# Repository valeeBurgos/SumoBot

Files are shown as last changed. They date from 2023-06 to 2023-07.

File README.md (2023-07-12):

# SumoBot
In this repository you will find all the information to build a sumo robot.

A sumo robot is a type of robot designed to compete in the sport of robotic sumo, a competition in which robots compete to push their opponent out of a circular ring using a variety of techniques and strategies. Sumo robots are generally small and round, with a large amount of power in their motors to forcefully push their opponent.

In robotic sumo competitions, robots must adhere to certain rules, such as the maximum size and weight allowed, and must be able to detect ring lines and avoid cheating. Sumo robots must also be able to operate autonomously during combat, as human controllers are not allowed in the ring.

### Hardware
In the "Hardware" folder you can find everything related to the physical development of the project, including the list of commercial materials, materials manufactured with indications and original files (for example, 3D printing), assembly instructions, observations and recommendations.
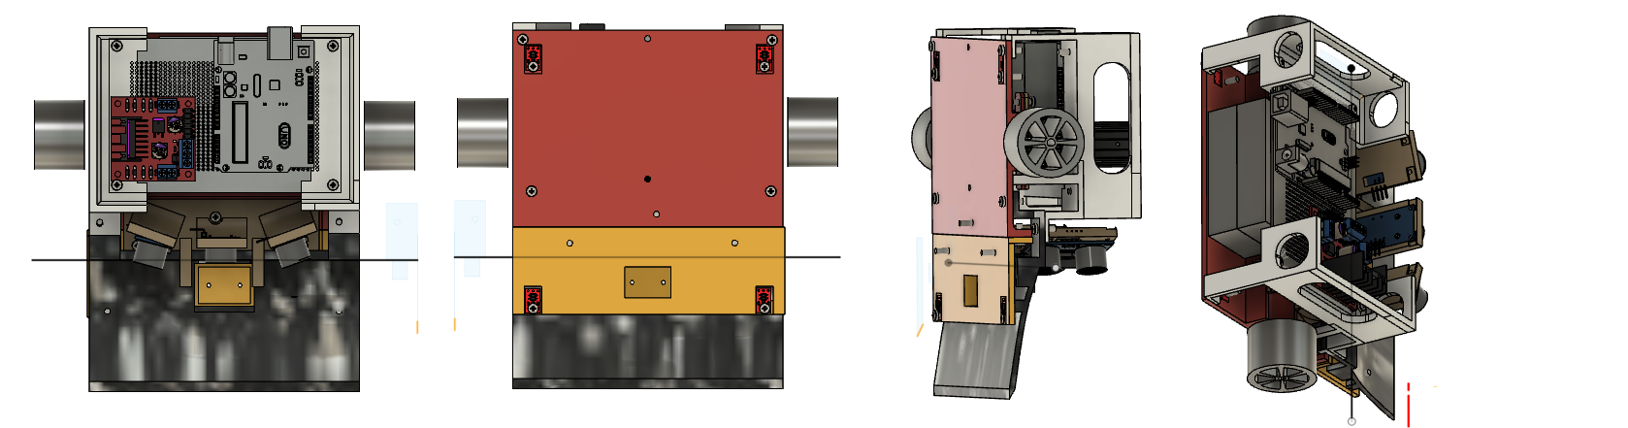
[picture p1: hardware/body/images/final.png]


### Software
In the "Software" folder you can find what is related to the code used. This is programmed in Arduino IDE and the algorithm will be explained in general terms.

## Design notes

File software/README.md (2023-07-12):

# SumoBot: body

Here is the code implemented for the robot.

### Technical details:
- UNO R3: Open-Source electronic board based on an ATMega microcontroller
- Programmed in Arduino IDE

### Pines
You can find all the information of the pins in the folder "circuit".

### Algorithm explanation

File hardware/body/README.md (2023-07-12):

# SumoBot: body

In this folder you will find everything you need to assemble the physical part of the robot discounting the circuit.
This includes (with images):
1. List of commercial components.
2. Links original files for 3D printing in GrabCAD.
3. Printing instructions
4. Assembly instructions.
6. Recommendations and observations

## Commercial components
- 1 x UNO R3 (UNO Full Microcontrolador Compatible, based on an ATmega microcontroller) (1)
- 2 x Motor Reductor 192rpm marca Troy modelo Luxor 25GA 12V (2)
- 1 x Driver L298N Puente H (3)
- 1 x Linear Regulator L7805CV  (4)
- 3 x Sensor Ultrasonico HC-SR04 (5)
- 3 x Push Button Momentary Switch 12mm (6)
- Floureon LiPo Battery 7,4 V 1500 mAh (7)
- 4 x analog Infrared reflective sensor 1-a (8)
- 1 x Universal protoboard (8 cm x 12 cm)  (9)
- mini 3PI car N20 Caster (10)
- Cabos  (11)
- 2 x conector T-DEAN (12)
- 24 x M3 x 10        (13)
- 24 x tuercas 3 mm   (14)
- 8 x M2 x 10         (15)
- 1 x resistor 47k    (16)

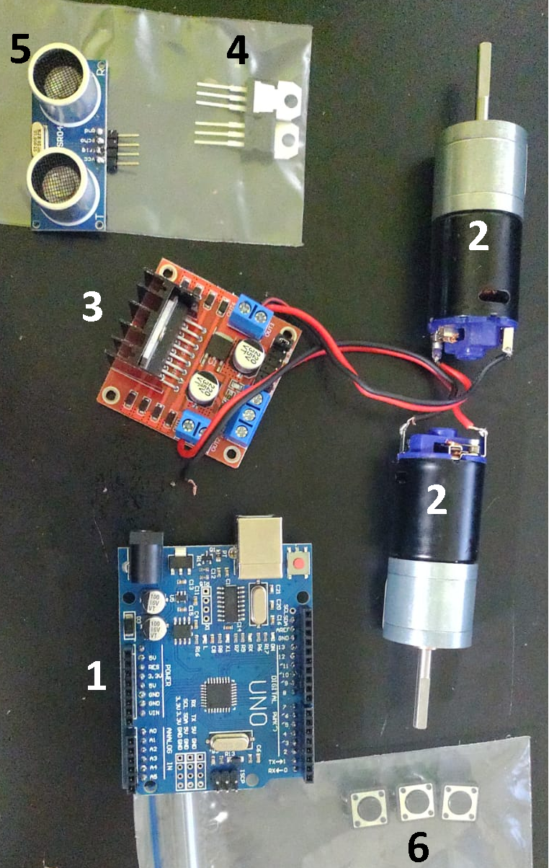
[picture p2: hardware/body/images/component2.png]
Component 2
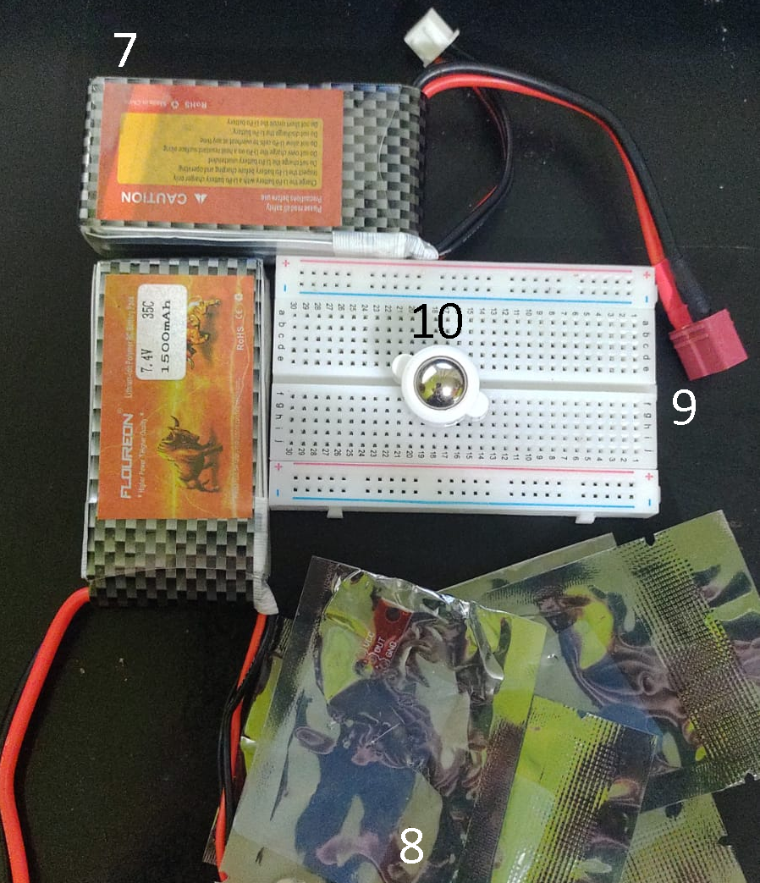
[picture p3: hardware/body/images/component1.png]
Component 1
|  |  |
| :---: | :---: |

## 3D components
To manufacture this robot, 3D printing was produced as the main manufacturing resource. Fusion360 was used to create the models, supporting commercial component models created by the community.

In [this link](https://grabcad.com/library/robot-sumo-10) you can find the necessary components, in .step and .f3d format (except those obtained from the community for commercial components that are only in .step format)

Inside the CAD folder you will find the following files:
- Base delantera (1)
- Base trasera (2)
- Soporte Ultrasonido (3)
- Rampa (4)
- Segundo piso 1 (5)
- Segundo piso 2 (6)
- Rueda (7) *
- Soporte motor (8) *

Whose number in parentheses corresponds to those labeled in the following image
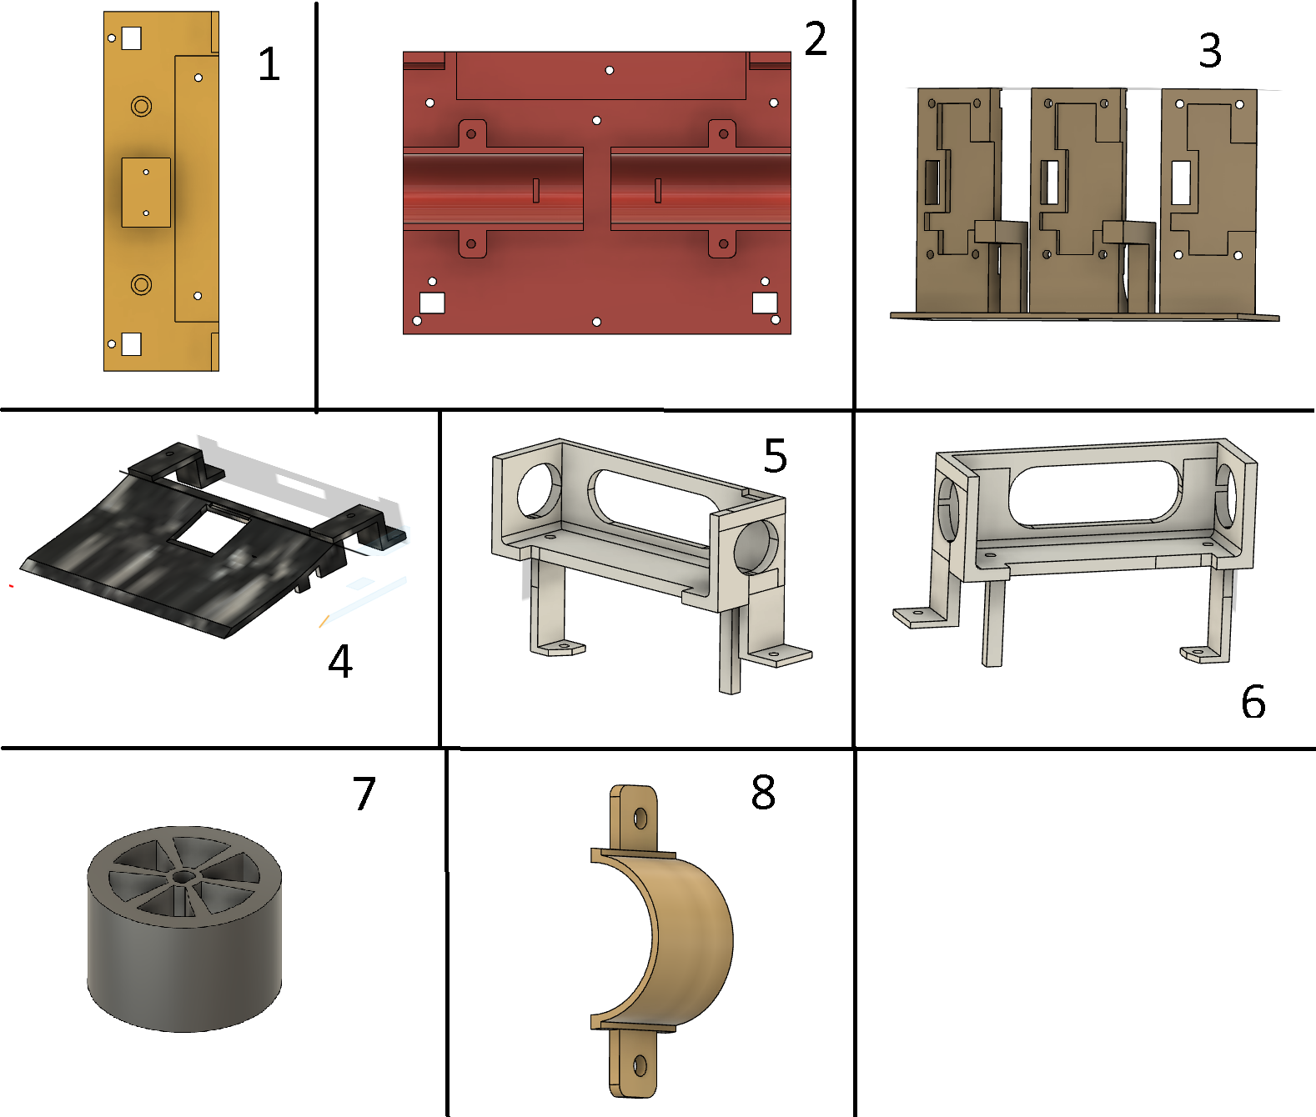
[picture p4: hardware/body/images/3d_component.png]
3D components


In the components folder you can find the commercial components used in .stl format. These are not to be printed, only used for a better visualization of the space.

## Printing instructions
To print these 8 components, it is considered that those marked with an * must be printed 2 times, since there are 2 wheels and motors that need support.

For this, an ender3 printer is used with the following parameters:
Wall : 2
Infill : 30%
Fill pattern :grid
Initial Layer Height : 0.28
Layer height : 0.32
Filament : PLA

The printing of all these pieces, in total, takes several hours. The files used are those that are in .stl format, so they do not need further adaptations.

## Assembly instructions
1. Base
As a first step, what can be seen in the image is assembled.
This corresponds to the following:
- 4 QTR-1d sensors to the base each with 1 bolt and nut M3 x 10
- Assemble the same to the ultrasonic sensor supports, using 4 M2 x10 bolts for each of the sensors.
- Motors on their respective supports held by part 8. 2 M3 x 10 nuts and bolts are used for each motor.
- The two parts of the base are joined with 2 M3 x 10 bolts with nuts.
- Piece 3 is joined with three M3 x 10 people. This piece also joins the two parts of the base.
The expected result is the one in the photo.
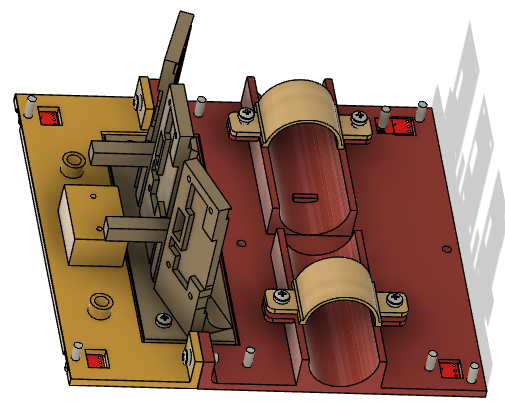
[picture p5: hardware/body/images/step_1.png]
1 step


2. First electrical connections

To each added sensor, use an arduino cable and connect it. Ideally, these connections should be soldered. For now, the other end is not connected.

3. Second layer of assembly
- In this step, pieces 5 and 6 are joined, which correspond to the second floor where the plate will be left. For this, 2 M3 x 10 bolts are used.
- Piece 4 is assembled. This is done by fitting the hole in the middle with the box of piece 1, in the lower part it has some cylinders that must be fitted with piece 1.
- Part 4 is joined to part 2 using 2 M3 x 10 bolts.
- Piece 4 is joined with pieces 5 and 6 with two M3 x10 buts.
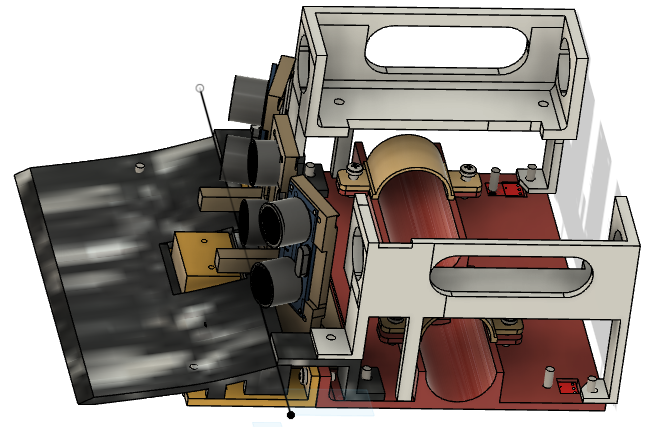
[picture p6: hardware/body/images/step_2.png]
3 step


4. Circuit in universal protoboard

The circuit is then prepared. For this, a universal breadboard is used.
- Solder microcontroller to breadboard. It is important to leave space on the arduino to upload the program, access must be easy.
- Solder L298N to the breadboard 
- A button is welding to the breadboard.
- Paths are made on the breadboard to join the elements as indicated in the instructions in the circuit folder.
- A small breadboard resting on part 2 is used to connect gnd and 5v to all the sensors.
- With arduino cables, the sensors are connected to the microcontroller.

Separately, connect the batteries in series. For this, piece 12 is used. If you have a single battery with sufficient voltage, this can be omitted. You must connect the ground with the rest of the circuit, connect the battery to the L298N and to the voltage regulator, from which the microcontroller and sensors are fed. 
In general, it is as follows:
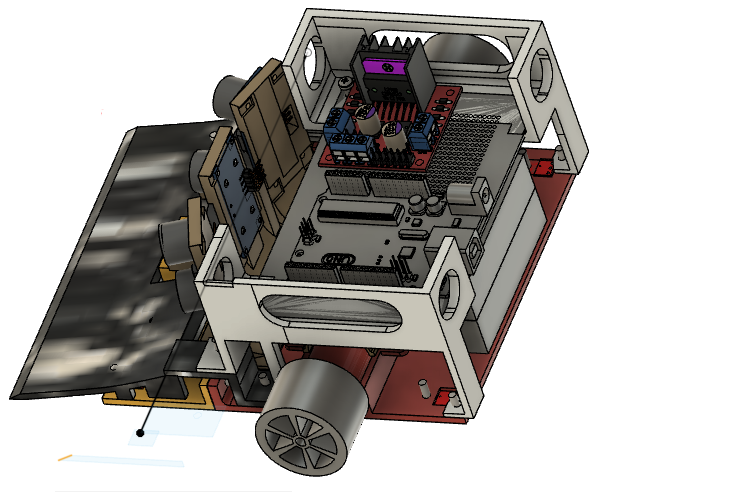
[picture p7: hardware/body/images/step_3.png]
4 step

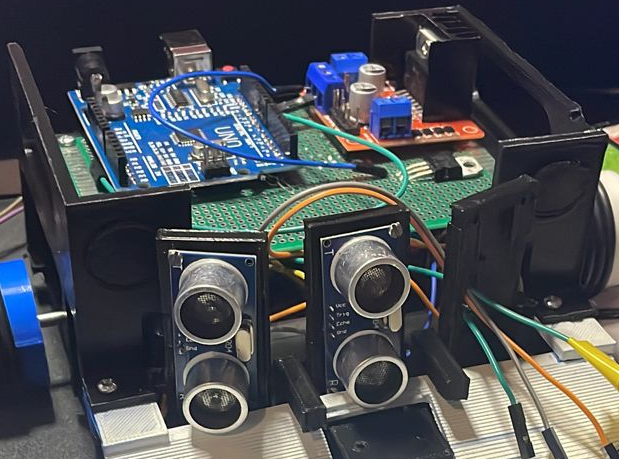
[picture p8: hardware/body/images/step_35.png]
4 step


5. Last step

Attach wheels to engines carefully.
Confirm that the battery is firm.
Secure the breadboard with 4 bolts to parts 5 and 6.  

## Recommendations and observations
- It is important to have separately reviewed the circuit. Care must be taken in the connections.
- Separately printed parts are weak, they must be handled with care. Once assembled the structure is much more resistant
- It is important to follow the order in which the elements are connected. Otherwise it may not be possible to locate bolts correctly due to small gaps.
- The box of part 1 is to locate some point of contact with the ground to manage stability. They serve many elements, but it is recommended to use the commercial component 10.
- The connections must be made at the indicated time or there is a risk of not having enough space, for example below the ramp there are 2 sensors that must be wired before positioning it.

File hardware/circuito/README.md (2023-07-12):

# SumoBot

In this folder you can find:
- A .pdf file named "sumo_circuit" with the connections of the circuit made in Kicad 6.0
- Explanation of the microcontroller pins used.
- Recommendations for the implementation of the circuit.

### components
Component specifications can be found in the list of commercial components [here](https://github.com/valeeBurgos/SumoBot/tree/main/hardware/body)

### Pins

The connections to the Arduino Uno R3 board are listed below. First, the digital pins are listed in order, followed by the analog pins.

Digital pins:
- 13 EchoM 
- 12 TrigL
- 11 EchoR
- 10 TrigR
- 9 ENA
- 8 IN1
- 7 IN2
- 6 EchoL
- 5 TrigM
- 4 IN4
- 3 ENB
- 2 IN3

Where the pins with the words Trig and Echo belong to ultrasound sensors. The letters that accompany it indicate its position: L is left, R right, M is middle.
The pins belonging to the system to control the motors are ENA, IN1, IN2, ENB, IN3, IN4.

Analog pins:
- A0 S1
- A1 S2
- A2 S3
- A3 S4
- A4 button

The connected pins correspond to the infrared sensors for line detection. In this case, they are digital pins but the analog inputs are used.
A button is also connected to an analog input.

### Notes
1. You can notice that almost all available pins of the place are used. If you want to add new elements, you must consider the space or change the microcontroller.
2. Infrared and ultrasonic sensors can interchange pins with respect to their same type. If these are interchanged, the code must be changed to ensure correct operation and expected behavior.
3. A 16V voltage is being used, but a 12V source is sufficient.
4. A regulator is used to go from 16V to 5V to power the microcontroller and sensors. It is important not to connect directly to 16V.
5. It is considered a good option to use a switch to control the power. It is not implemented in this circuit.

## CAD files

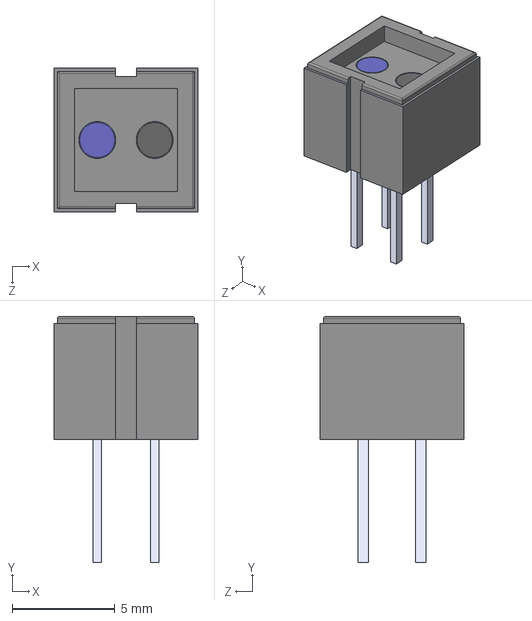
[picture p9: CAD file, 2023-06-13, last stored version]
hardware/circuito/librerias/CNY70/CNY70.step
7.00 x 12.0 x 7.00 mm

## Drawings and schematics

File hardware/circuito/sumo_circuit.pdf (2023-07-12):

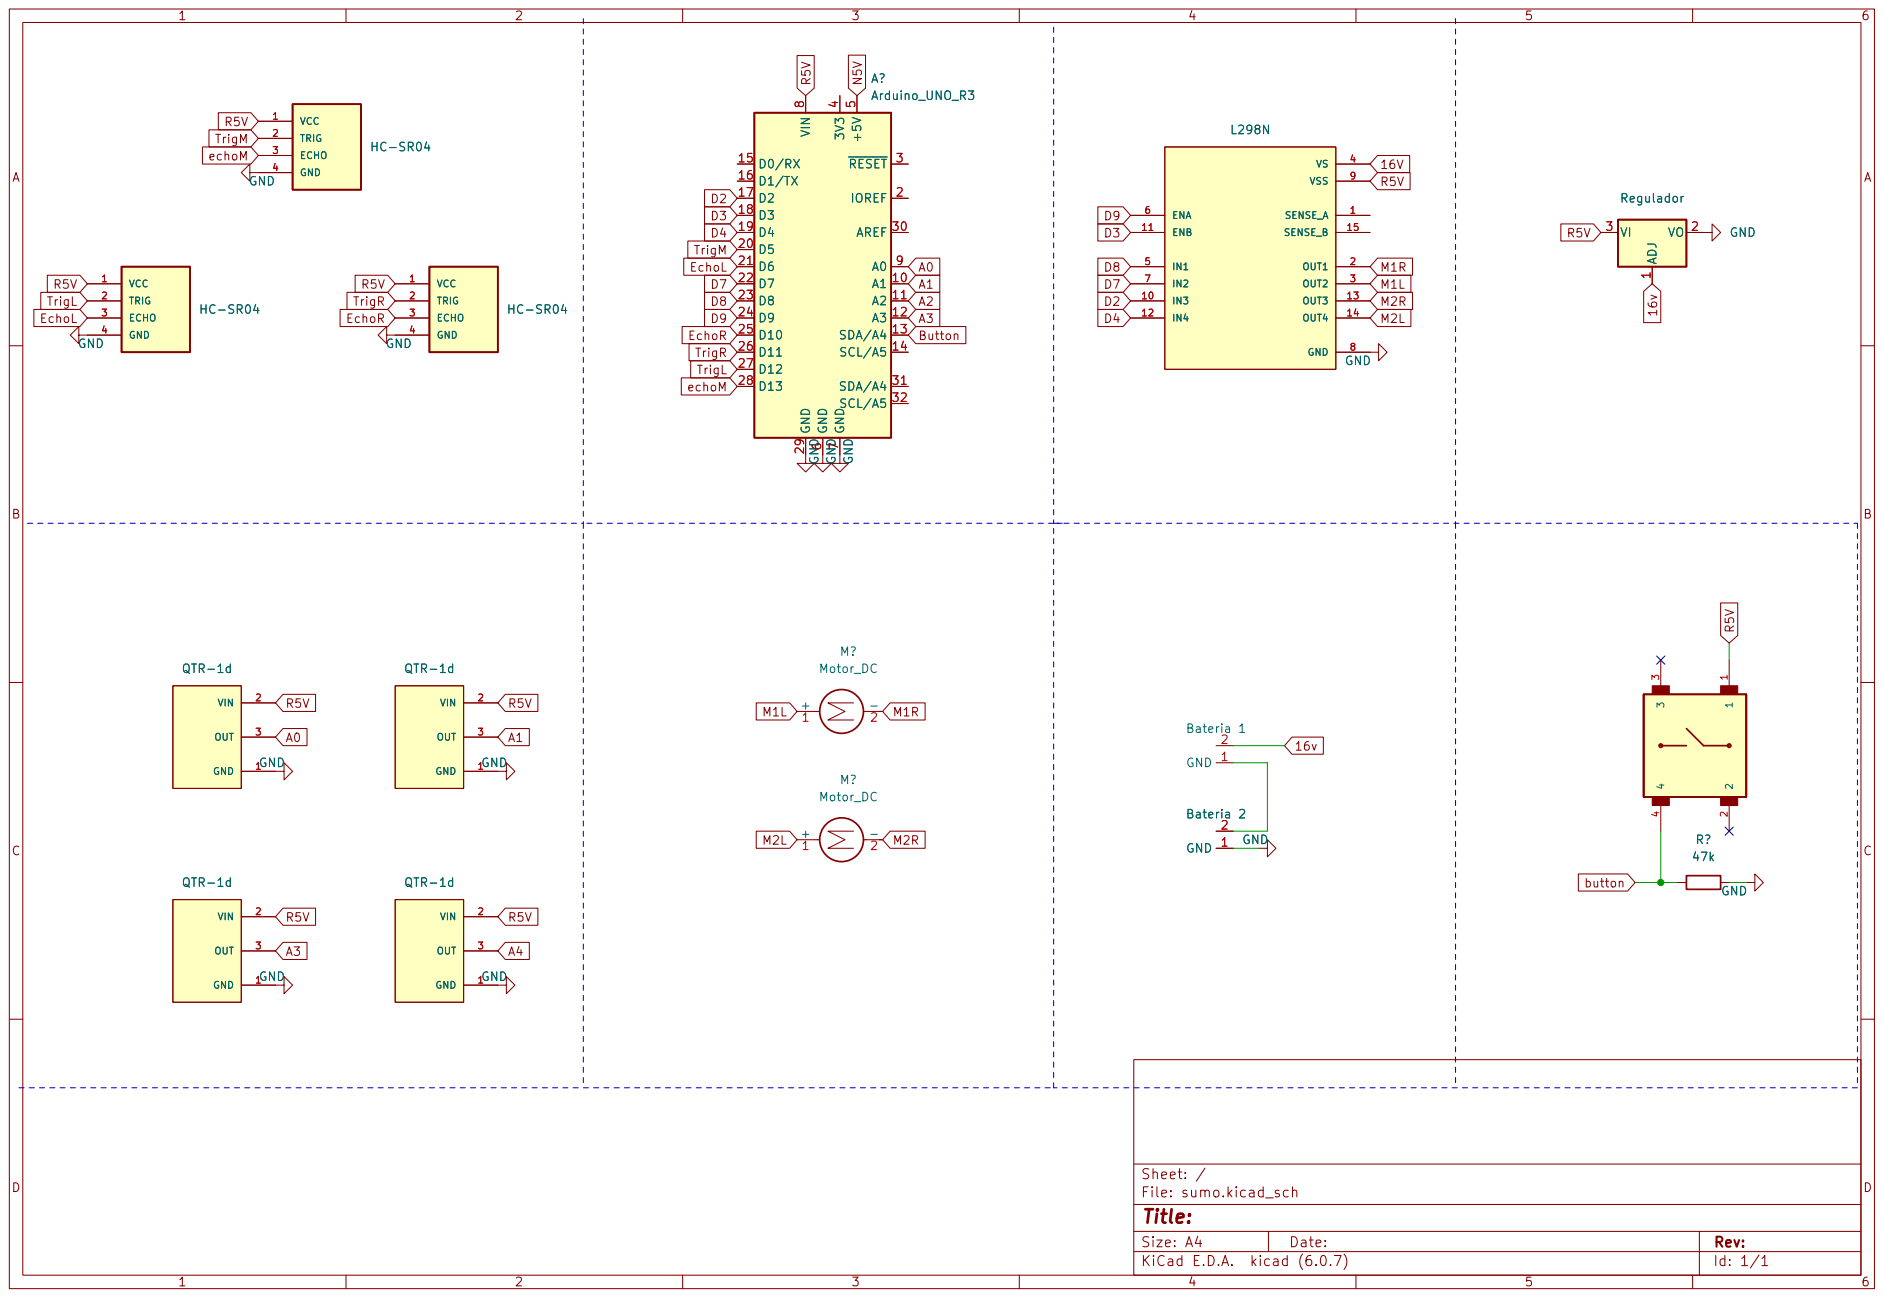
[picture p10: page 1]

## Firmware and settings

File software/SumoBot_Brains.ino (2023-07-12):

#include <Button.h>
//Status
int Status = 0;
//Button
Button button1(A4);
//Middle Sonar
int echoM = 13;
int trigM = 5;
int dM = 0;

//Left Sonar
int echoL = 6;
int trigL = 12;
int dL = 0;

//Right Sonar
int echoR = 11;
int trigR = 10;
int dR = 0;

// Motor A connections
int enA = 9;
int in1 = 8;
int in2 = 7;
// Motor B connections
int enB = 3;
int in3 = 2;
int in4 = 4;

void setup() {
  //Pin Declaration
  pinMode(trigM, OUTPUT);
  pinMode(echoM, INPUT);
  pinMode(trigL, OUTPUT);
  pinMode(echoL, INPUT);
  pinMode(trigR, OUTPUT);
  pinMode(echoR, INPUT);
  pinMode(enA, OUTPUT);
	pinMode(enB, OUTPUT);
	pinMode(in1, OUTPUT);
	pinMode(in2, OUTPUT);
	pinMode(in3, OUTPUT);
	pinMode(in4, OUTPUT);
  digitalWrite(in1, LOW);
	digitalWrite(in2, LOW);
	digitalWrite(in3, LOW);
	digitalWrite(in4, LOW);
  button1.begin();
  Serial.begin(9600);

}

void loop() {
  if(Status==0){
    if (button1.pressed()){
      Status = 1;
      Serial.println("Fight Mode Activated");
      delay(4000);
    }
    else{
      Serial.println("ready");
      delay(200);
    }
  }
  if (Status == 1){
    if(button1.pressed()){
      Status = 0;
      digitalWrite(enB, 0);
	    digitalWrite(in3, LOW);
	    digitalWrite(in4, LOW);
      digitalWrite(enA, 0);
	    digitalWrite(in1, LOW);
	    digitalWrite(in2, LOW);
      Serial.println("Fight Mode Deactivated");
      delay(10);
    }
    else{
      //get distance for all sensors
      dM = getDistance(trigM, echoM);
      Serial.println(dM);
      delayMicroseconds(10);
      dL = getDistance(trigL, echoL);
      delayMicroseconds(10);
      dR = getDistance(trigR, echoR);
      Serial.println(dR);
      delayMicroseconds(10);
      //print to Monitor where (Left, Middle, Right) the opponent is
      Action(dL,dM,dR);
      delay(50);
    }
  }
}
//getDistance: INT, INT -> INT
//Takes the pins of the sensor and returns the distance of the object to 
//  that sensor 
int getDistance(int triggerPin, int echoPin){
  digitalWrite(triggerPin, HIGH);
  delayMicroseconds(10);
  digitalWrite(triggerPin, LOW);
  unsigned long pulseTime = pulseIn(echoPin, HIGH);
  int distance = pulseTime/58;
  return distance;
}
//recon: INT, INT, INT -> None
//Takes the distance from the 3 sensors and prints to Serial an array where the
//  position of the 1 indicates where is the nearest obstacle. in case no 
//  obstacle is detected, prints NO DETECTION
void Action(int leftDistance, int middleDistance, int rightDistance){
  if (leftDistance >= 100 && middleDistance >= 100 && rightDistance >= 100){
    Serial.println("NO DETECTION");
    digitalWrite(enA, 255);
	  digitalWrite(in1, LOW);
	  digitalWrite(in2, HIGH);
    digitalWrite(enB, 255);
	  digitalWrite(in3, HIGH);
	  digitalWrite(in4, LOW);
    delayMicroseconds(10);
  }
  else{
    int dirL = min(min(leftDistance,middleDistance),rightDistance)/leftDistance;
    int dirR = min(min(leftDistance,middleDistance),rightDistance)/rightDistance;
    int dirM = 1 - max(dirL, dirR);

    Serial.print(dirL);
    Serial.print("|");
    Serial.print(dirM);
    Serial.print("|");
    Serial.print(dirR);
    Serial.println();


   if(dirM == 1){
      digitalWrite(enA, 255);
	    digitalWrite(in1, HIGH);
	    digitalWrite(in2, LOW);
      digitalWrite(enB, 255);
	    digitalWrite(in3, HIGH);
	    digitalWrite(in4, LOW);
      delayMicroseconds(10);
    }
    if (dirR == 1){
      digitalWrite(enA, 255);
	    digitalWrite(in1, HIGH);
	    digitalWrite(in2, LOW);
      digitalWrite(enB, 100);
	    digitalWrite(in3, HIGH);
	    digitalWrite(in4, LOW);
      delayMicroseconds(10);
    }
    if (dirL == 1){
      digitalWrite(enA, 100);
	    digitalWrite(in1, HIGH);
	    digitalWrite(in2, LOW);
      digitalWrite(enB, 255);
	    digitalWrite(in3, HIGH);
	    digitalWrite(in4, LOW);
      delayMicroseconds(10);
    }
  }
}

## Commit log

2023-06-13 Añadir readme a circuito
2023-06-13 Se comienza el circuito usando kicad
    [CNY70.step, Placa.kicad_pcb, Placa.kicad_sch]
2023-06-21 Added coded Recon Algorithm for 3 ultrasonic sensors
    Still needs to transfer the detection of direcction to usable variable
2023-06-22 Recon circuit schematic
2023-06-29 update documentation
    [CNY70.step, Placa.kicad_pcb, Placa.kicad_sch]
2023-07-12 update circuit information
2023-07-12 Code for SumoBot Without IR Sensors
